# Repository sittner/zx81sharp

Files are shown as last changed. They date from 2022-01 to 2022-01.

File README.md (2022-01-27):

# zx81sharp

This is essentially a redraw of Mahjongg's great [ZX81plus38](https://github.com/mahjongg2/ZX81plus38) project.
I've done it to be able to fix and modify some issues:

* fixed pinout of tape connectors CO2/CO3
* fixed rotation/position of keyboard connector J3
* fixed CPU clock phase
* fixed position of connectors and mounting holes
* replaced USB power connector with  2.1/2.5 mm power plug
* simplified memory address decoder to allow full usage of RAM/ROM memory
* fixed video output sync latch to avoid ghost lines

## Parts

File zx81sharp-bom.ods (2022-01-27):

Item | Qty | Reference(s) | Value | Footprint | Dist | PartNo
1 | 2 | C1, C2 | 4p7 | Capacitor_THT:C_Disc_D3.0mm_W2.0mm_P2.50mm
2 | 1 | C3 | 4n7 | Capacitor_THT:C_Disc_D4.7mm_W2.5mm_P5.00mm
3 | 1 | C5 | 1u | Capacitor_THT:C_Disc_D4.7mm_W2.5mm_P5.00mm
4 | 13 | C6, C10, C11, C12, C13, C14, C15, C16, C17, C18, C19, C20, C21 | 100n | Capacitor_THT:C_Disc_D4.7mm_W2.5mm_P5.00mm
5 | 2 | C7, C8 | 47p | Capacitor_THT:C_Disc_D4.7mm_W2.5mm_P5.00mm
6 | 1 | C9 | 100u | Capacitor_THT:CP_Radial_D6.3mm_P2.50mm
7 | 1 | CO1 | Power in | modusoft:Jack_Barrel_CLIFF_FCR681465P
8 | 1 | CO2 | Tape out | modusoft:Jack_3.5mm_MULTICOMP_SPC21348
9 | 1 | CO3 | Tape in | modusoft:Jack_3.5mm_MULTICOMP_SPC21348
10 | 1 | CO4 | Joystick | Connector_Dsub:DSUB-9_Male_Horizontal_P2.77x2.84mm_EdgePinOffset7.70mm_Housed_MountingHolesOffset9.12mm
11 | 1 | CO5 | Video out | modusoft:RCA_CON_CLIFF_FC68391
12 | 9 | D1, D2, D3, D4, D5, D6, D7, D8, D14 | 1N4148 | Diode_THT:D_DO-35_SOD27_P7.62mm_Horizontal
13 | 1 | D13 | BAT43 | Diode_THT:D_DO-35_SOD27_P7.62mm_Horizontal
14 | 5 | H1, H2, H3, H4, H7 | MountingHole 3.0mm | MountingHole:MountingHole_3mm
15 | 2 | H5, H6 | MountingHole 2.5mm | MountingHole:MountingHole_2.5mm
16 | 1 | J1 | LED on | Connector_PinHeader_2.54mm:PinHeader_1x02_P2.54mm_Vertical
17 | 1 | J2 | KB2 | Connector_PinSocket_2.54mm:PinSocket_1x08_P2.54mm_Vertical
18 | 1 | J3 | KB1 | Connector_PinSocket_2.54mm:PinSocket_1x05_P2.54mm_Vertical
19 | 1 | J11 | Expansion Header | modusoft:ZX81_EXP
20 | 1 | J12 | Expansion Header | Connector_PinHeader_2.54mm:PinHeader_2x23_P2.54mm_Vertical
21 | 1 | JP2 | Jumper_2_Open | Connector_PinHeader_2.54mm:PinHeader_1x02_P2.54mm_Vertical
22 | 1 | JP4 | 60Hz | Connector_PinHeader_2.54mm:PinHeader_1x02_P2.54mm_Vertical
23 | 1 | JP5 | Invert | Connector_PinHeader_2.54mm:PinHeader_1x03_P2.54mm_Vertical
24 | 1 | JP6 | Border | Connector_PinHeader_2.54mm:PinHeader_1x03_P2.54mm_Vertical
25 | 3 | JP8, JP9, JP11 | Jumper_3_Bridged12 | Connector_PinHeader_2.54mm:PinHeader_1x03_P2.54mm_Vertical
26 | 7 | Q1, Q2, Q3, Q4, Q5, Q8, Q9 | 2N3904 | Package_TO_SOT_THT:TO-92
27 | 18 | R1, R2, R3, R4, R5, R6, R7, R8, R9, R10, R11, R12, R13, R14, R15, R16, R17, R58 | 1k | Resistor_THT:R_Axial_DIN0207_L6.3mm_D2.5mm_P2.54mm_Vertical
28 | 6 | R18, R19, R23, R52, R59, R81 | 10k | Resistor_THT:R_Axial_DIN0207_L6.3mm_D2.5mm_P2.54mm_Vertical
29 | 3 | R20, R42, R43 | 680R | Resistor_THT:R_Axial_DIN0207_L6.3mm_D2.5mm_P2.54mm_Vertical
30 | 1 | R21 | 330R | Resistor_THT:R_Axial_DIN0207_L6.3mm_D2.5mm_P7.62mm_Horizontal
31 | 1 | R29 | 2M2 | Resistor_THT:R_Axial_DIN0207_L6.3mm_D2.5mm_P7.62mm_Horizontal
32 | 2 | R30, R49 | 1k | Resistor_THT:R_Axial_DIN0207_L6.3mm_D2.5mm_P7.62mm_Horizontal
33 | 1 | R48 | 470R | Resistor_THT:R_Axial_DIN0207_L6.3mm_D2.5mm_P7.62mm_Horizontal
34 | 2 | R50, R55 | 100R | Resistor_THT:R_Axial_DIN0207_L6.3mm_D2.5mm_P7.62mm_Horizontal
35 | 1 | R56 | 47k | Resistor_THT:R_Axial_DIN0207_L6.3mm_D2.5mm_P2.54mm_Vertical
36 | 1 | R57 | 2k2 | Resistor_THT:R_Axial_DIN0207_L6.3mm_D2.5mm_P2.54mm_Vertical
37 | 1 | R70 | 220k | Resistor_THT:R_Axial_DIN0207_L6.3mm_D2.5mm_P2.54mm_Vertical
38 | 1 | R79 | 82k | Resistor_THT:R_Axial_DIN0207_L6.3mm_D2.5mm_P2.54mm_Vertical
39 | 1 | R80 | 220R | Resistor_THT:R_Axial_DIN0207_L6.3mm_D2.5mm_P2.54mm_Vertical
40 | 1 | RP1 | 10k | Resistor_THT:R_Array_SIP7
41 | 1 | RP2 | 22k | Resistor_THT:R_Array_SIP9
42 | 2 | U1, U22 | 74HC541 | Package_DIP:DIP-20_W7.62mm_Socket_LongPads
43 | 1 | U2 | Z80CPU | Package_DIP:DIP-40_W15.24mm_Socket_LongPads
44 | 1 | U3 | KM62256CLP | Package_DIP:DIP-28_W15.24mm_Socket_LongPads
45 | 1 | U4 | 74HC574 | Package_DIP:DIP-20_W7.62mm_Socket_LongPads
46 | 1 | U5 | 27C256 | Package_DIP:DIP-28_W15.24mm_Socket_LongPads
47 | 1 | U6 | 74HC125 | Package_DIP:DIP-14_W7.62mm_Socket_LongPads
48 | 2 | U7, U14 | 74HC393 | Package_DIP:DIP-14_W7.62mm_Socket_LongPads
49 | 1 | U8 | 74HC4002 | Package_DIP:DIP-14_W7.62mm_Socket_LongPads
50 | 1 | U9 | 74HC165 | Package_DIP:DIP-16_W7.62mm_Socket_LongPads
51 | 1 | U10 | 74HC86 | Package_DIP:DIP-14_W7.62mm_Socket_LongPads
52 | 2 | U11, U24 | 74HC08 | Package_DIP:DIP-14_W7.62mm_Socket_LongPads
53 | 4 | U12, U16, U19, U23 | 74HC32 | Package_DIP:DIP-14_W7.62mm_Socket_LongPads
54 | 1 | U13 | 74HC00 | Package_DIP:DIP-14_W7.62mm_Socket_LongPads
55 | 1 | U15 | 74HC11 | Package_DIP:DIP-14_W7.62mm_Socket_LongPads
56 | 3 | U18, U28, U29 | 74HC74 | Package_DIP:DIP-14_W7.62mm_Socket_LongPads
57 | 1 | U21 | 74HC14 | Package_DIP:DIP-14_W7.62mm_Socket_LongPads
58 | 1 | U27 | 74HC138 | Package_DIP:DIP-16_W7.62mm_Socket_LongPads
59 | 1 | Y1 | 13MHz | Crystal:Crystal_HC49-4H_Vertical

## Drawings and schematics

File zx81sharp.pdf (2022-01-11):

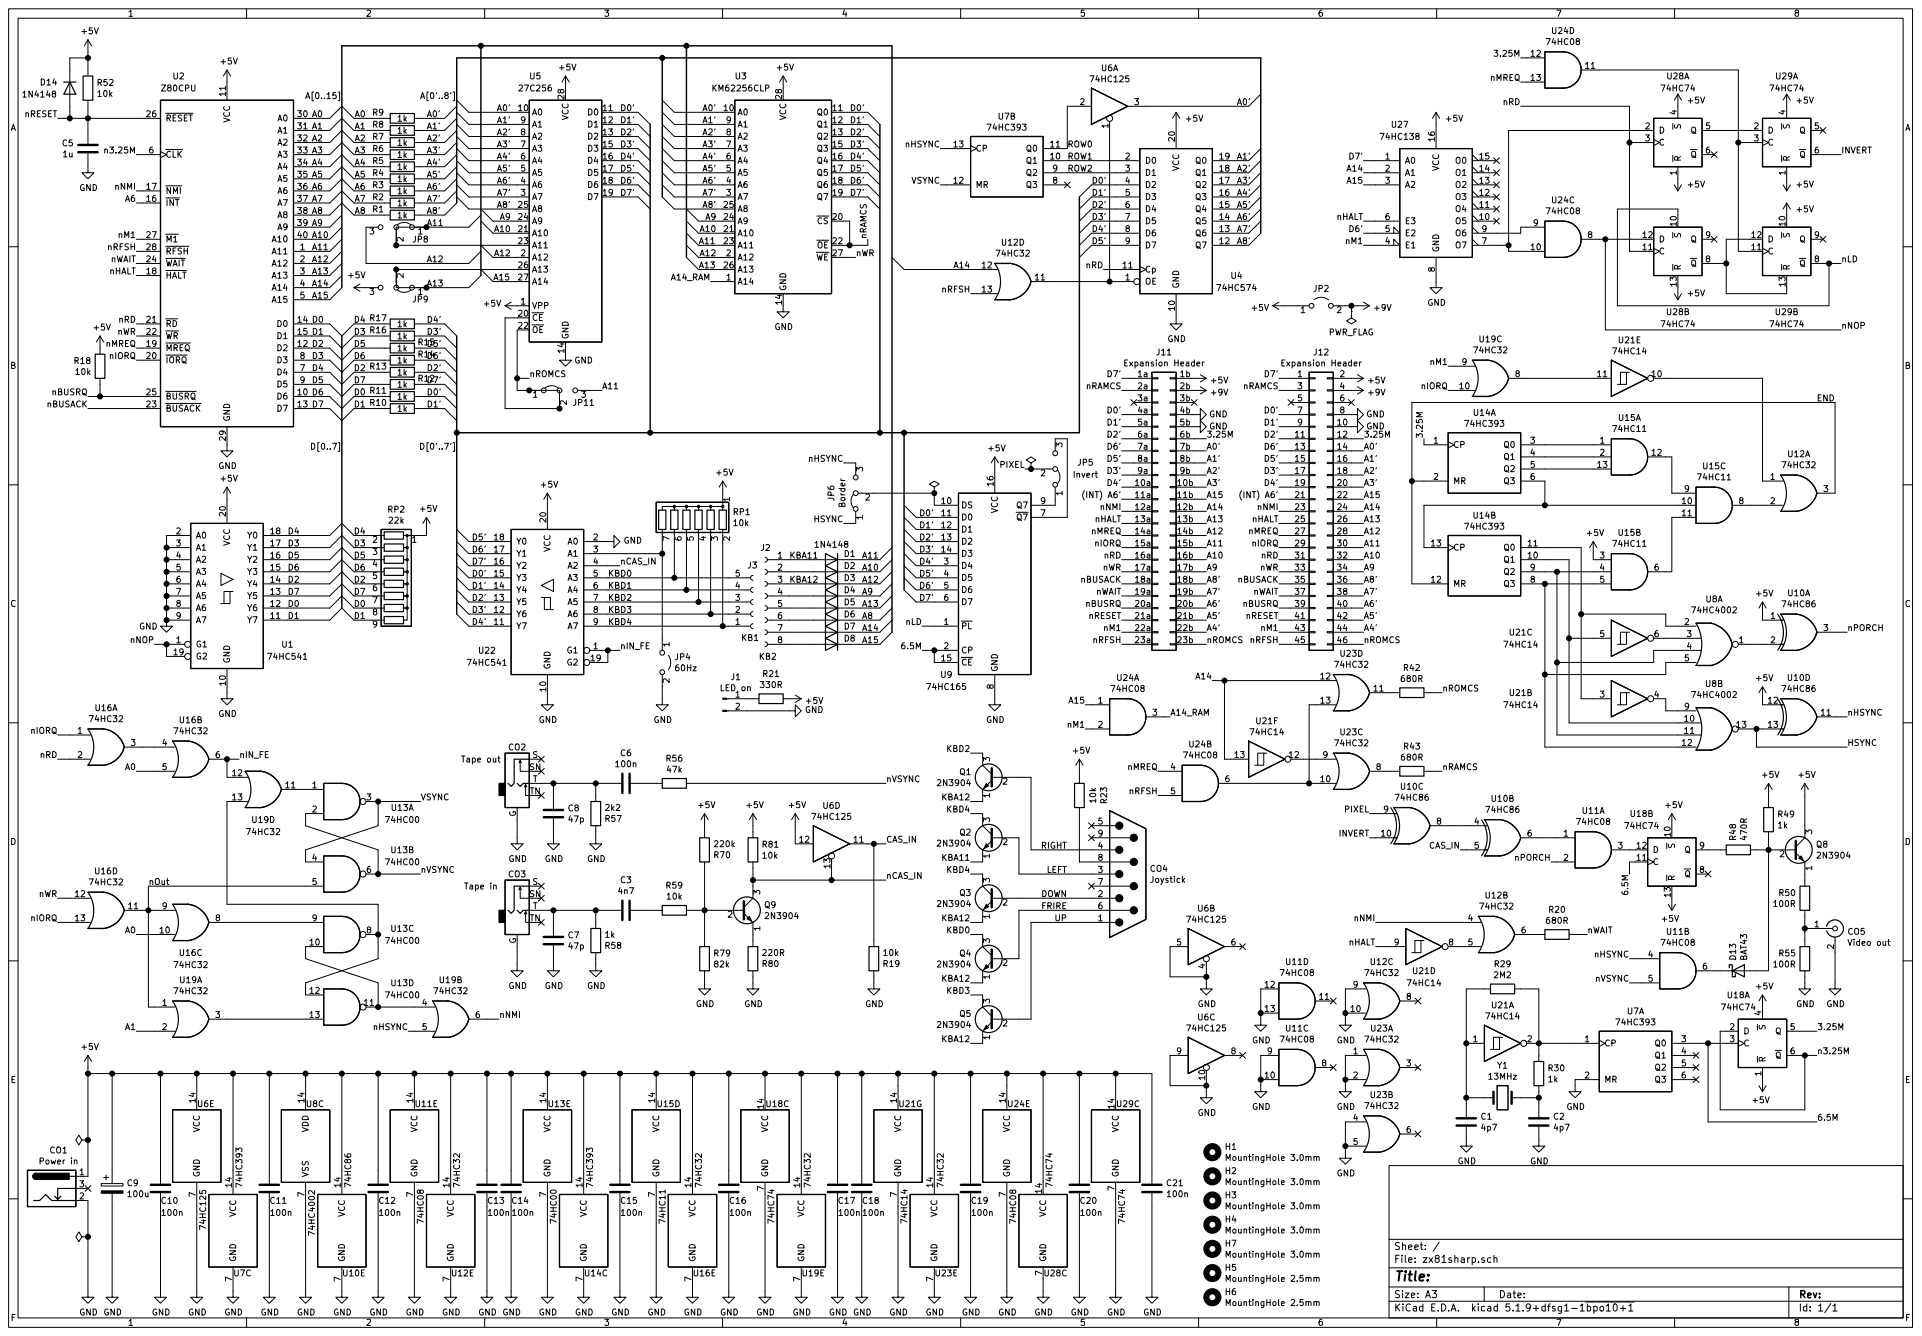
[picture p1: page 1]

2 CO5 Video out VCC 14 GND

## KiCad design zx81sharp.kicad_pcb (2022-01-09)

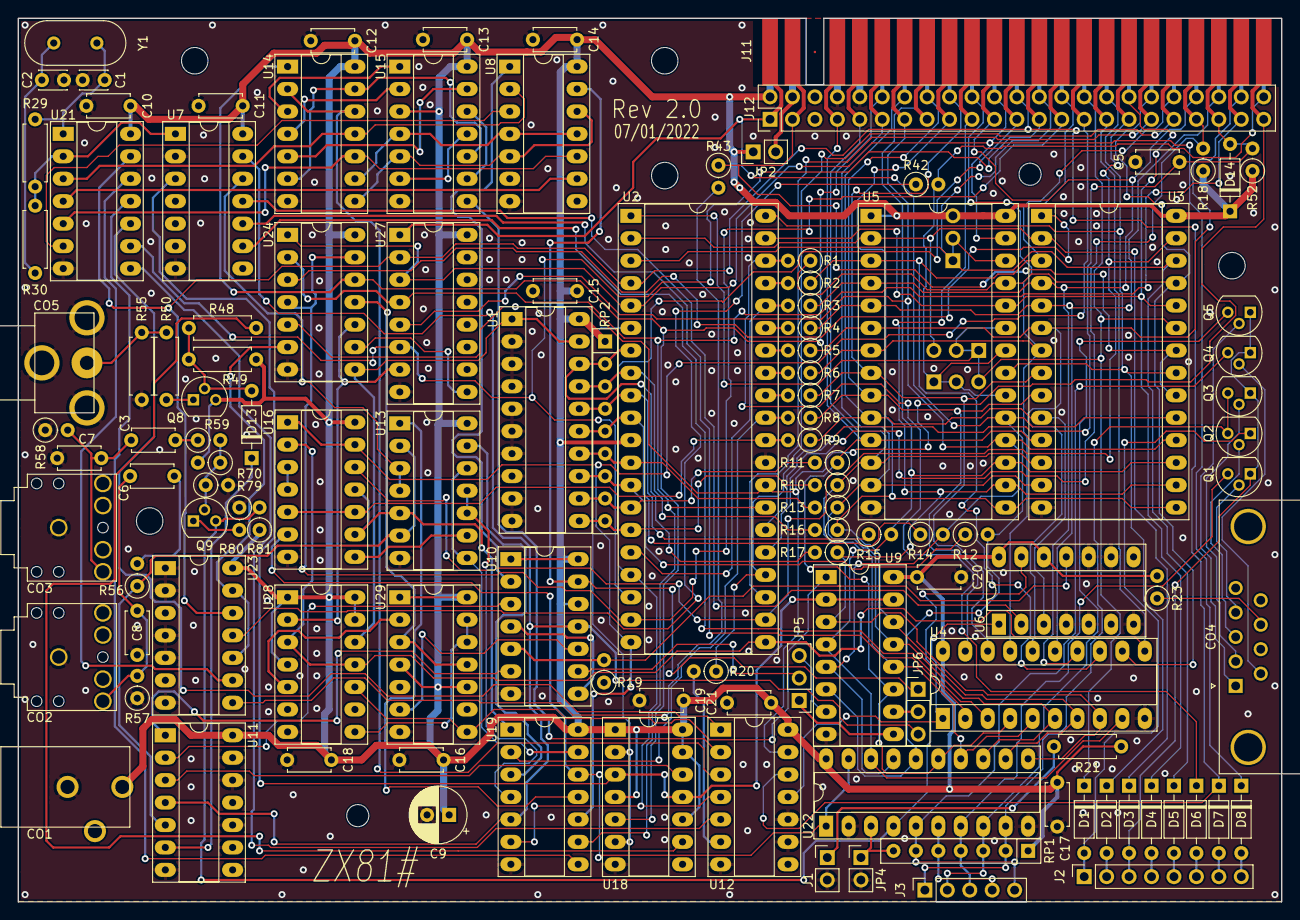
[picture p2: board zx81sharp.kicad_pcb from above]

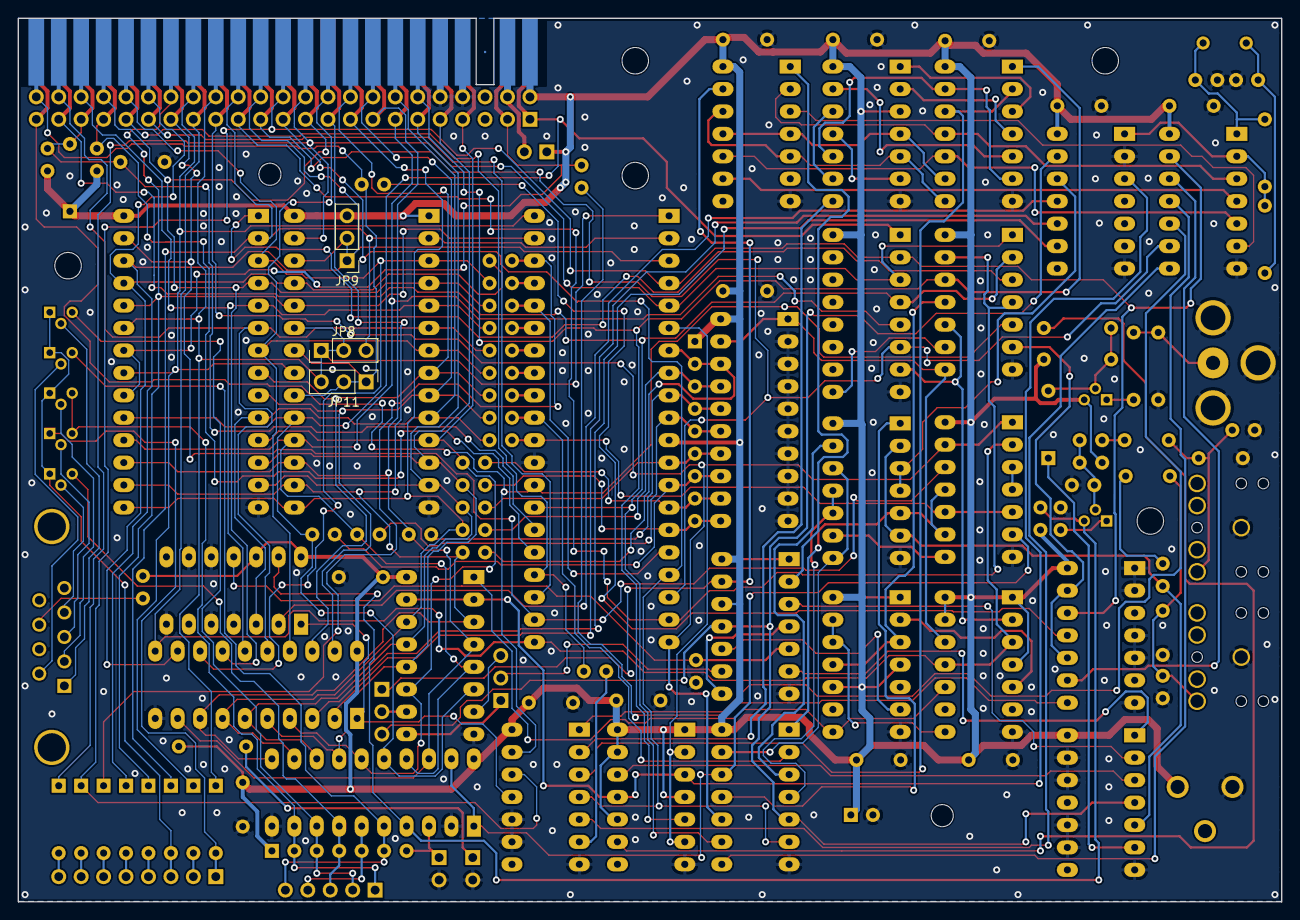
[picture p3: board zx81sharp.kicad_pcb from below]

Board: 2 copper layers, 143.0 x 100.0 mm, 128 parts (3 on the bottom side), 154 nets.

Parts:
C1, C2: 4p7; C_Disc_D3.0mm_W2.0mm_P2.50mm
C3: 4n7; C_Disc_D4.7mm_W2.5mm_P5.00mm
C5: 1u; C_Disc_D4.7mm_W2.5mm_P5.00mm
C6, C10, C11, C12, C13, C14, C15, C16, C17, C18, C19, C20, C21: 100n; C_Disc_D4.7mm_W2.5mm_P5.00mm
C7, C8: 47p; C_Disc_D4.7mm_W2.5mm_P5.00mm
C9: 100u; CP_Radial_D6.3mm_P2.50mm
CO1: Power in; Jack_Barrel_CLIFF_FCR681465P
CO2: Tape out; Jack_3.5mm_MULTICOMP_SPC21348
CO3: Tape in; Jack_3.5mm_MULTICOMP_SPC21348
CO4: Joystick; DSUB-9_Male_Horizontal_P2.77x2.84mm_EdgePinOffset7.70mm_Hou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
CO5: Video out; RCA_CON_CLIFF_FC68391
D1, D2, D3, D4, D5, D6, D7, D8, D14: 1N4148; D_DO-35_SOD27_P7.62mm_Horizontal
D13: BAT43; D_DO-35_SOD27_P7.62mm_Horizontal
H1, H2, H3, H4, H7: MountingHole 3.0mm; MountingHole_3mm
H5, H6: MountingHole 2.5mm; MountingHole_2.5mm
J1: LED on; PinHeader_1x02_P2.54mm_Vertical
J2: KB2; PinSocket_1x08_P2.54mm_Vertical
J3: KB1; PinSocket_1x05_P2.54mm_Vertical
J11: Expansion Header; ZX81_EXP
J12: Expansion Header; PinHeader_2x23_P2.54mm_Vertical
JP2: Jumper_2_Open; PinHeader_1x02_P2.54mm_Vertical
JP4: 60Hz; PinHeader_1x02_P2.54mm_Vertical
JP5: Invert; PinHeader_1x03_P2.54mm_Vertical
JP6: Border; PinHeader_1x03_P2.54mm_Vertical
JP8, JP9, JP11: Jumper_3_Bridged12; PinHeader_1x03_P2.54mm_Vertical
Q1, Q2, Q3, Q4, Q5, Q8, Q9: 2N3904; TO-92
R1, R2, R3, R4, R5, R6, R7, R8, R9, R10, R11, R12, R13, R14, R15, R16, R17, R58: 1k; R_Axial_DIN0207_L6.3mm_D2.5mm_P2.54mm_Vertical
R18, R19, R23, R52, R59, R81: 10k; R_Axial_DIN0207_L6.3mm_D2.5mm_P2.54mm_Vertical
R20, R42, R43: 680R; R_Axial_DIN0207_L6.3mm_D2.5mm_P2.54mm_Vertical
R21: 330R; R_Axial_DIN0207_L6.3mm_D2.5mm_P7.62mm_Horizontal
R29: 2M2; R_Axial_DIN0207_L6.3mm_D2.5mm_P7.62mm_Horizontal
R30, R49: 1k; R_Axial_DIN0207_L6.3mm_D2.5mm_P7.62mm_Horizontal
R48: 470R; R_Axial_DIN0207_L6.3mm_D2.5mm_P7.62mm_Horizontal
R50, R55: 100R; R_Axial_DIN0207_L6.3mm_D2.5mm_P7.62mm_Horizontal
R56: 47k; R_Axial_DIN0207_L6.3mm_D2.5mm_P2.54mm_Vertical
R57: 2k2; R_Axial_DIN0207_L6.3mm_D2.5mm_P2.54mm_Vertical
R70: 220k; R_Axial_DIN0207_L6.3mm_D2.5mm_P2.54mm_Vertical
R79: 82k; R_Axial_DIN0207_L6.3mm_D2.5mm_P2.54mm_Vertical
R80: 220R; R_Axial_DIN0207_L6.3mm_D2.5mm_P2.54mm_Vertical
RP1: 10k; R_Array_SIP7
RP2: 22k; R_Array_SIP9
U1, U22: 74HC541; DIP-20_W7.62mm_Socket_LongPads
U2: Z80CPU; DIP-40_W15.24mm_Socket_LongPads
U3: KM62256CLP; DIP-28_W15.24mm_Socket_LongPads
U4: 74HC574; DIP-20_W7.62mm_Socket_LongPads
U5: 27C256; DIP-28_W15.24mm_Socket_LongPads
U6: 74HC125; DIP-14_W7.62mm_Socket_LongPads
U7, U14: 74HC393; DIP-14_W7.62mm_Socket_LongPads
U8: 74HC4002; DIP-14_W7.62mm_Socket_LongPads
U9: 74HC165; DIP-16_W7.62mm_Socket_LongPads
U10: 74HC86; DIP-14_W7.62mm_Socket_LongPads
U11, U24: 74HC08; DIP-14_W7.62mm_Socket_LongPads
U12, U16, U19, U23: 74HC32; DIP-14_W7.62mm_Socket_LongPads
U13: 74HC00; DIP-14_W7.62mm_Socket_LongPads
U15: 74HC11; DIP-14_W7.62mm_Socket_LongPads
U18, U28, U29: 74HC74; DIP-14_W7.62mm_Socket_LongPads
U21: 74HC14; DIP-14_W7.62mm_Socket_LongPads
U27: 74HC138; DIP-16_W7.62mm_Socket_LongPads
Y1: 13MHz; Crystal_HC49-4H_Vertical

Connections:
+5V: C9.1, C10.1, C11.1, C12.1, C13.1, C14.1, C15.1, C16.1, C17.1, C18.1, C19.1, C20.1, C21.1, CO1.1, D14.1, J11.1b, J12.2, JP2.1, JP9.3, Q8.3, R18.1, R21.1, R23.2, R49.1, R52.1, R70.2, R81.1, RP1.1, RP2.1, U1.20, U2.11, U3.28, U4.20, U5.1, U5.28, U6.12, U6.14, U7.14, U8.14, U9.16, U10.1, U10.12, U10.14, U11.14, U12.14, U13.14, U14.14, U15.3, U15.14, U16.14, U18.1, U18.4, U18.10, U18.13, U18.14, U19.14, U21.14, U22.20, U23.14, U24.14, U27.16, U28.1, U28.4, U28.13, U28.14, U29.1, U29.4, U29.10, U29.14
+9V: J11.2b, J12.4, JP2.2
/3.25M: J11.6b, J12.12, U14.1, U18.5, U24.12
/6.5M: U7.3, U9.2, U9.15, U18.3, U18.11
/A0: R9.2, U2.30, U16.5, U16.10
/A0': J11.7b, J12.14, R9.1, U3.10, U5.10, U6.3
/A1: R8.2, U2.31, U19.2
/A1': J11.8b, J12.16, R8.1, U3.9, U4.19, U5.9
/A2: R7.2, U2.32
/A2': J11.9b, J12.18, R7.1, U3.8, U4.18, U5.8
/A3: R6.2, U2.33
/A3': J11.10b, J12.20, R6.1, U3.7, U4.17, U5.7
/A4: R5.2, U2.34
/A4': J11.22b, J12.44, R5.1, U3.6, U4.16, U5.6
/A5: R4.2, U2.35
/A5': J11.21b, J12.42, R4.1, U3.5, U4.15, U5.5
/A6: R3.2, U2.16, U2.36
/A6': J11.11a, J11.20b, J12.21, J12.40, R3.1, U3.4, U4.14, U5.4
/A7: R2.2, U2.37
/A7': J11.19b, J12.38, R2.1, U3.3, U4.13, U5.3
/A8: D6.1, R1.2, U2.38
/A8': J11.18b, J12.36, R1.1, U3.25, U4.12, U5.25
/A9: D4.1, J11.17b, J12.34, U2.39, U3.24, U5.24
/A10: D2.1, J11.16b, J12.32, U2.40, U3.21, U5.21
/A11: D1.1, J11.15b, J12.30, JP8.1, JP8.2, JP11.3, U2.1, U3.23, U5.23
/A12: D3.1, J11.14b, J12.28, JP8.3, U2.2, U3.2, U5.2
/A13: D5.1, J11.13b, J12.26, JP9.1, JP9.2, U2.3, U3.26, U5.26
/A14: D7.1, J11.12b, J12.24, U2.4, U12.12, U21.13, U23.12, U27.2
/A14_RAM: U3.1, U24.3
/A15: D8.1, J11.11b, J12.22, U2.5, U5.27, U24.1, U27.3
/CAS_IN: R19.2, U6.11, U10.5
/D0: R11.2, RP2.8, U1.12, U2.14
/D0': J11.4a, J12.7, R11.1, U3.11, U4.4, U5.11, U9.11, U22.15
/D1: R10.2, RP2.9, U1.11, U2.15
/D1': J11.5a, J12.9, R10.1, U3.12, U4.5, U5.12, U9.12, U22.14
/D2: R13.2, RP2.6, U1.14, U2.12
/D2': J11.6a, J12.11, R13.1, U3.13, U4.6, U5.13, U9.13, U22.13
/D3: R16.2, RP2.3, U1.17, U2.8
/D3': J11.9a, J12.17, R16.1, U3.15, U4.7, U5.15, U9.14, U22.12
/D4: R17.2, RP2.2, U1.18, U2.7
/D4': J11.10a, J12.19, R17.1, U3.16, U4.8, U5.16, U9.3, U22.11
/D5: R15.1, RP2.4, U1.16, U2.9
/D5': J11.8a, J12.15, R15.2, U3.17, U4.9, U5.17, U9.4, U22.18
/D6: R14.1, RP2.5, U1.15, U2.10
/D6': J11.7a, J12.13, R14.2, U3.18, U5.18, U9.5, U22.17, U27.5
/D7: R12.1, RP2.7, U1.13, U2.13
/D7': J11.1a, J12.1, R12.2, U3.19, U5.19, U9.6, U22.16, U27.1
/DOWN: CO4.2, Q3.2
/END: U12.3, U14.2, U14.12
/FRIRE: CO4.6, Q4.2
/HSYNC: JP6.1, U8.13, U10.13
/INVERT: U10.10, U29.6
/KBA11: D1.2, J2.1, Q2.1
/KBA12: D3.2, J2.3, Q1.1, Q3.1, Q4.1, Q5.1
/KBD0: J3.5, Q4.3, RP1.6, U22.5
/KBD1: J3.4, RP1.5, U22.6
/KBD2: J3.3, Q1.3, RP1.4, U22.7
/KBD3: J3.2, Q5.3, RP1.3, U22.8
/KBD4: J3.1, Q2.3, Q3.3, RP1.2, U22.9
/LEFT: CO4.3, Q2.2
/PIXEL: JP5.2, U10.9
/RIGHT: CO4.4, Q1.2
/ROW0: U6.2, U7.11
/ROW1: U4.2, U7.10
/ROW2: U4.3, U7.9
/UP: CO4.1, Q5.2
/VSYNC: U7.12, U13.3, U13.4
/n3.25M: U2.6, U18.2, U18.6
/nBUSACK: J11.18a, J12.35, U2.23
/nBUSRQ: J11.20a, J12.39, R18.2, U2.25
/nCAS_IN: Q9.3, R81.2, U6.13, U22.4
/nHALT: J11.13a, J12.25, U2.18, U21.9, U27.6
/nHSYNC: JP6.3, U7.13, U10.11, U11.4, U19.5
/nIN_FE: U16.6, U19.12, U22.1, U22.19
/nIORQ: J11.15a, J12.29, U2.20, U16.1, U16.13, U19.10
/nLD: U9.1, U28.10, U29.8
/nM1: J11.22a, J12.43, U2.27, U19.9, U24.2, U27.4
/nMREQ: J11.14a, J12.27, U2.19, U24.4, U24.13
/nNMI: J11.12a, J12.23, U2.17, U12.4, U19.6
/nNOP: U1.1, U1.19, U24.8, U28.12
/nOut: U13.5, U16.9, U16.11, U19.1
/nPORCH: U10.3, U11.2
/nRAMCS: J11.2a, J12.3, R43.1, U3.20, U3.22
/nRD: J11.16a, J12.31, U2.21, U4.11, U16.2, U28.3, U28.11
/nRESET: C5.1, D14.2, J11.21a, J12.41, R52.2, U2.26
/nRFSH: J11.23a, J12.45, U2.28, U12.13, U24.5
/nROMCS: J11.23b, J12.46, JP11.1, JP11.2, R42.2, U5.20, U5.22
/nVSYNC: R56.1, U11.5, U13.2, U13.6
/nWAIT: J11.19a, J12.37, R20.1, U2.24
/nWR: J11.17a, J12.33, U2.22, U3.27, U16.12
GND: C1.2, C2.2, C5.2, C7.2, C8.2, C9.2, C10.2, C11.2, C12.2, C13.2, C14.2, C15.2, C16.2, C17.2, C18.2, C19.2, C20.2, C21.2, CO1.2, CO2.G, CO3.G, CO5.2, J1.2, J11.4b, J11.5b, J12.8, J12.10, JP4.2, R19.1, R55.2, R57.1, R58.1, R79.2, R80.1, U1.2, U1.3, U1.4, U1.5, U1.6, U1.7, U1.8, U1.9, U1.10, U2.29, U3.14, U4.10, U5.14, U6.4, U6.5, U6.7, U6.9, U6.10, U7.2, U7.7, U8.7, U9.8, U10.7, U11.7, U11.9, U11.10, U11.12, U11.13, U12.7, U12.9, U12.10, U13.7, U14.7, U15.7, U16.7, U18.7, U19.7, U21.7, U22.2, U22.10, U23.1, U23.2, U23.4, U23.5, U23.7, U24.7, U27.8, U28.7, U29.7
unnamed: C1.1, R29.2, U21.1, Y1.1
unnamed: C2.1, R30.2, Y1.2
unnamed: C3.1, R59.1
unnamed: C3.2, C7.1, CO3.T, R58.2
unnamed: C6.1, R56.2
unnamed: C6.2, C8.1, CO2.T, R57.2
unnamed: CO4.8, R23.1
unnamed: CO5.1, R50.2, R55.1
unnamed: D2.2, J2.2
unnamed: D4.2, J2.4
unnamed: D5.2, J2.5
unnamed: D6.2, J2.6
unnamed: D7.2, J2.7
unnamed: D8.2, J2.8
unnamed: D13.1, U11.6
unnamed: D13.2, Q8.2, R48.2, R49.2
unnamed: J1.1, R21.2
unnamed: JP4.1, RP1.7, U22.3
unnamed: JP5.1, U9.9
unnamed: JP5.3, U9.7
unnamed: JP6.2, U9.10
unnamed: Q8.1, R50.1
unnamed: Q9.1, R80.2
unnamed: Q9.2, R59.2, R70.1, R79.1
unnamed: R20.2, U12.6
unnamed: R29.1, R30.1, U7.1, U21.2
unnamed: R42.1, U23.11
unnamed: R43.2, U23.8
unnamed: R48.1, U18.9
unnamed: U8.1, U10.2
unnamed: U10.4, U10.8
unnamed: U10.6, U11.1
unnamed: U11.3, U18.12
unnamed: U12.1, U21.10
unnamed: U12.2, U15.8
unnamed: U12.5, U21.8
unnamed: U4.1, U6.1, U12.11
unnamed: U13.1, U19.11
unnamed: U13.9, U16.8
unnamed: U13.10, U13.11, U19.4
unnamed: U13.8, U13.12, U19.13
unnamed: U13.13, U19.3
unnamed: U14.3, U15.1
unnamed: U14.4, U15.2
unnamed: U14.5, U15.13
unnamed: U8.5, U8.12, U14.8, U15.5
unnamed: U8.4, U8.11, U14.9, U15.4
unnamed: U8.10, U14.10, U21.5
unnamed: U8.2, U14.11, U21.3
unnamed: U14.6, U14.13, U15.10
unnamed: U15.6, U15.11
unnamed: U15.9, U15.12
unnamed: U16.3, U16.4
unnamed: U19.8, U21.11
unnamed: U8.9, U21.4
unnamed: U8.3, U21.6
unnamed: U21.12, U23.9
unnamed: U23.10, U23.13, U24.6
unnamed: U24.9, U27.9
unnamed: U24.10, U27.7, U28.2
unnamed: U24.11, U29.3, U29.11
unnamed: U28.5, U29.2
unnamed: U28.8, U29.12, U29.13

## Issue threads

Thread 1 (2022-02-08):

74HC(T)14

inschenioer, 2022-02-08:
When cleaning up the design you should also consider replacing the 74HC(T)14 by a 74HC(T)04.

Schmitt-Triggers are a really bad idea in Pierce-Oscillators. My ZX81+38 did not work until I used a 74HCT04. The oscillator output was ANYTHING from several 100 kHz, 1.3 MHz, 6.xx MHz etc., but the desired clean 13 MHz signal, no matter what 13 MHz-XTAL I used (had a couple of them from different sources).

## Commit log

2022-01-05 fixed mounting hole positions
    [zx81plus38.kicad_pcb, zx81plus38.sch]
2022-01-05 fixed keyboard connector
    [zx81plus38.kicad_pcb, zx81plus38.sch]
2022-01-07 fixed CPU clock, memory decoder and video output latch
    [zx81plus38.kicad_pcb, zx81plus38.sch]
2022-01-08 finished rev 2.0
    [zx81plus38.kicad_pcb, zx81plus38.sch]
2022-01-09 renamed project to zx81sharp
    [zx81sharp.kicad_pcb, zx81sharp.sch]
2022-01-11 cosmetic fixes
    [zx81sharp.sch]
2022-01-27 added initial BOM
    [zx81sharp-bom.ods]
